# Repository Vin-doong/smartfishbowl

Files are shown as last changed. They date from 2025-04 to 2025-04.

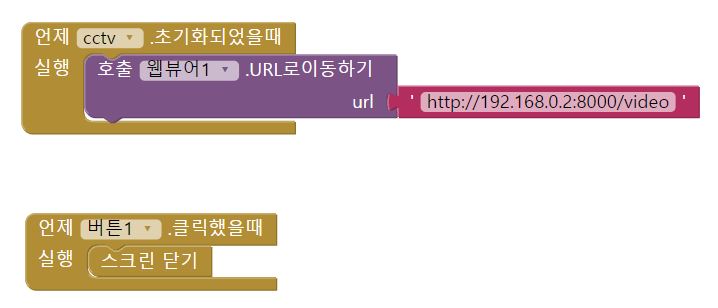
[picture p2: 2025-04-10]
앱제작파일/블록도/스마트어항CCTV.JPG

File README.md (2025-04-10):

# 스마트 어항 (Smart Fishbowl)

라즈베리파이를 활용한 IoT 기반 스마트 어항 시스템으로, 각종 센서를 통해 어항 환경을 모니터링하고 자동/수동으로 관리할 수 있습니다.

## 개요

집에서 물고기를 키우면서 항상 관리에 대한 어려움이 있습니다. 일상생활을 하면서 종종 물고기 먹이를 주는 것을 잊거나 물갈이 등을 잊어버릴 때가 있습니다. 어항 관리를 좀 더 편하게 하기 위해 스마트 어항이라는 작품을 개발했습니다.

사료 공급, 탁도 조절, 수위 체크 등 물고기를 키울 때 필요한 요소들을 라즈베리파이를 기반으로 자동화했습니다.

## 주요 기능

### 수동 모드
1. **센서값 모니터링**: 수위, 조도, 수온, 탁도, 온습도 센서값 출력
   - 새로고침 버튼 클릭 시 센서값 실시간 업데이트
2. **모터 수동 제어**: 
   - 먹이 공급 모터
   - 물 순환 모터
   - 물 공급 모터
3. **LED 조작**: ON/OFF 버튼으로 LED 제어
4. **CCTV 기능**: 파이카메라를 통한 물고기 실시간 관찰
5. **데이터 디스플레이**: 센서값을 LCD 및 앱에 표시

### 자동 모드
1. **조도 센서 기반 LED 제어**: 일정 조도값에 따라 자동으로 LED ON/OFF
2. **수위 센서 기반 물 공급 제어**: 일정 수위값에 도달 시 물 공급 모터 자동 동작
3. **탁도 센서 기반 물 순환 제어**: 일정 탁도값에 도달 시 물 순환 모터 자동 동작

## 하드웨어 구성요소

- 라즈베리파이 (메인 컨트롤러)
- 모터 드라이버 (L298N)
- 서보 모터 (사료 공급용)
- DC 모터 (물 순환 및 물 공급용)
- 각종 센서:
  - 수위 센서
  - 조도 센서
  - 수온 센서 (DS18B20)
  - 탁도 센서
  - 온습도 센서 (DHT11)
- LCD 디스플레이 (I2C)
- LED 조명
- 파이카메라
- PCF8591 ADC 컨버터 (아날로그 센서 인터페이스)

## 소프트웨어 구성

### 백엔드
- Python 기반 Flask 웹 서버
- GPIO 제어 라이브러리
- 센서 데이터 수집 및 처리 모듈
- 자동 제어 알고리즘

### 프론트엔드
- 모바일 애플리케이션 (MIT App Inventor로 개발)
- HTML/CSS 웹 인터페이스 (CCTV 화면용)

## 설치 및 실행 방법

1. 라즈베리파이에 필요한 라이브러리 설치:
```bash
sudo apt-get update
sudo apt-get install python3-pip
pip3 install flask
pip3 install Adafruit_DHT
pip3 install smbus
pip3 install picamera2
pip3 install opencv-python
pip3 install numpy
pip3 install pillow
```

2. 하드웨어 연결:
   - GPIO 핀 연결은 코드 내 설정 참조 (GPIO 5, 6, 13, 19, 21, 26 등 사용)
   - I2C 연결 (LCD, PCF8591)
   - 1-Wire 설정 (수온 센서용)

3. 코드 실행:
```bash
python3 finalfinalwork.py
```

4. 모바일 앱 설치:
   - App Inventor로 제작된 APK 파일 설치

## 코드 설명

### 메인 코드 (finalfinalwork.py)

메인 코드는 다음과 같은 섹션으로 구성되어 있습니다:

1. **라이브러리 임포트 및 초기화**
   - Flask, GPIO, 센서 라이브러리 등 임포트
   - GPIO 설정 및 PWM 초기화

2. **센서 데이터 수집 함수**
   - 각 센서별 데이터 읽기 함수
   - 온습도 센서를 위한 스레드 설정

3. **카메라 스트리밍 설정**
   - Picamera2 설정 및 프레임 캡처 함수

4. **웹 라우트 설정**
   - 메인 페이지, 자동 모드, 수동 모드, CCTV 등 엔드포인트 정의
   - 센서 데이터 표시 및 모터 제어 로직

### LCD 드라이버 (I2C_LCD_driver.py)

I2C를 통한 LCD 디스플레이 제어를 위한 드라이버 코드입니다.

### HTML 템플릿 (index4#2.html)

CCTV 기능을 위한 웹 인터페이스 HTML 파일입니다.

## 3D 프린팅 설계

프로젝트에는 다음과 같은 3D 프린팅 컴포넌트가 포함되어 있습니다:
- 파이카메라 거치대
- LED 거치대 및 LED 바
- LCD 케이스
- 컨트롤박스
- 먹이공급 케이스
- 물통 등

## 네트워크 통신

- TCP/IP 기반 통신
- 포트포워딩을 통한 외부 접속 지원
- Flask 웹서버를 통한 API 제공

## 앱 인터페이스

모바일 앱은 다음과 같은 기능을 제공합니다:
- 센서값 실시간 모니터링
- 수동 모드에서 각 컴포넌트 제어
- 자동 모드 활성화/비활성화
- CCTV 화면 보기

## 제작자

- 김상현(조장)
- 이순민

## 참고자료

- [VNC 화면설정](https://www.youtube.com/watch?v=LlXx9yVfQ0k)
- [PCF8591 사용법](https://blog.naver.com/tiled12/221791735227)
- [Picamera 작동](https://www.youtube.com/watch?v=kuJpdAf07WQ)
- [라즈베리파이 코드 자동실행](https://eggwhite0.tistory.com/73)
- [GPIO 라이브러리](https://abyz.me.uk/rpi/pigpio/index.html)
- [파이카메라 CCTV활용](https://www.youtube.com/watch?v=Y3IdUiFYhe8)
- [플라스크 예제](https://scribblinganything.tistory.com/400)
- [포트포워딩 설정](https://m.blog.naver.com/dsz08082/221871200736)

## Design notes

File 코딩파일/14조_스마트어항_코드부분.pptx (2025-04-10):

## 스마트 어항 (Smart Fishbowl)

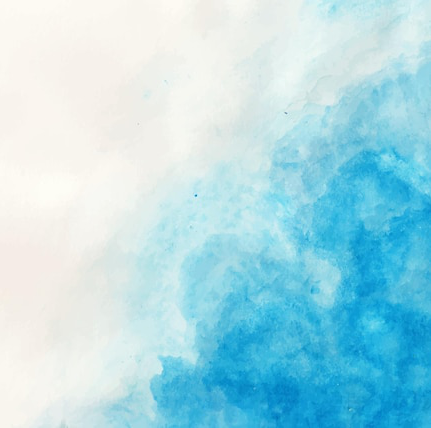
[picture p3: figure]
무료 벡터 블루 자세한 배경으로 수채화

조원:20202727 김상현
20201554 이순민

## Python 부분

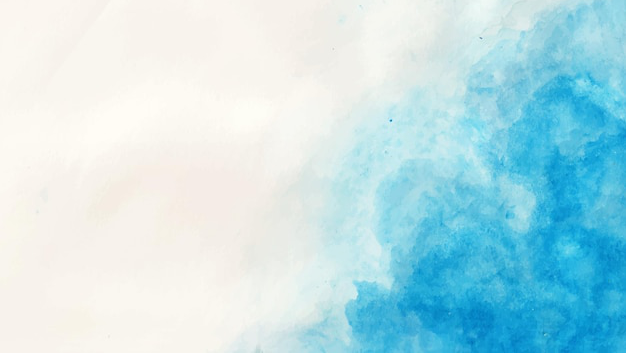
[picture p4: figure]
무료 벡터 블루 자세한 배경으로 수채화

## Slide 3

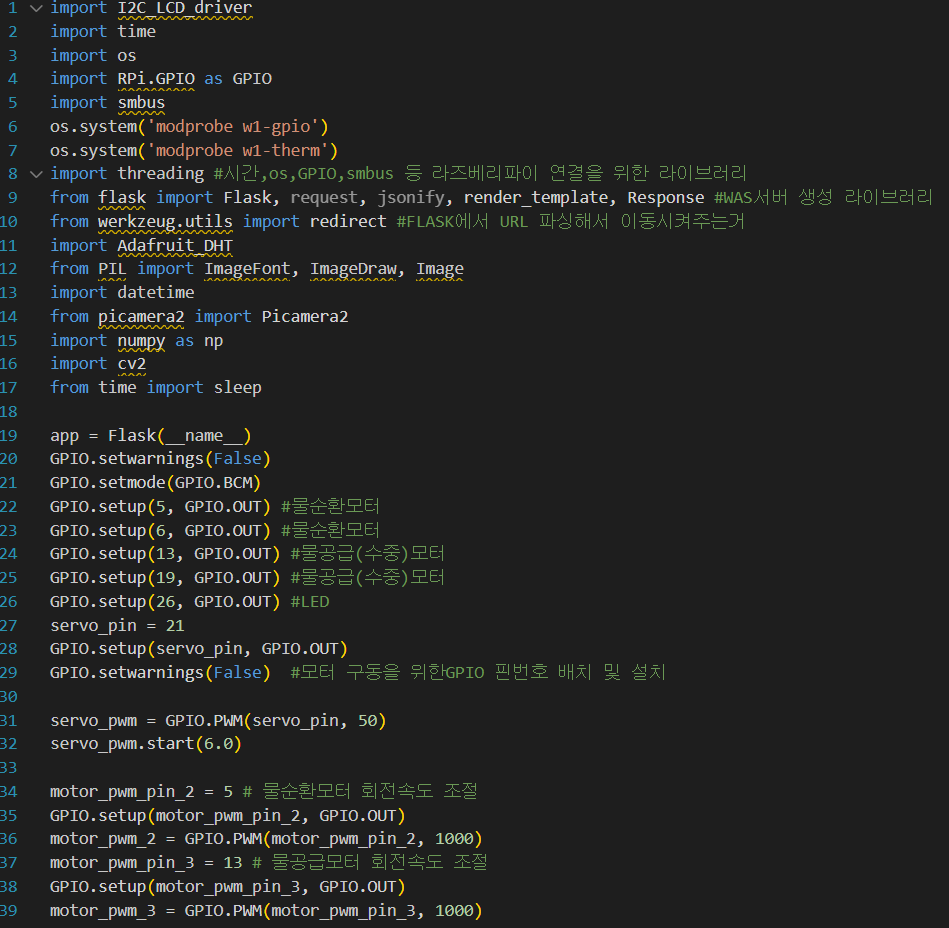
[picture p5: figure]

1~17 : 스마트 어항에 필요한 라이브러리 호출
19 : flask 웹 애플리케이션 서버 만들기 시작
21~39 : 모터 및 LED 셋업, 물순환, 물공급모터 회전속도 조절

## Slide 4

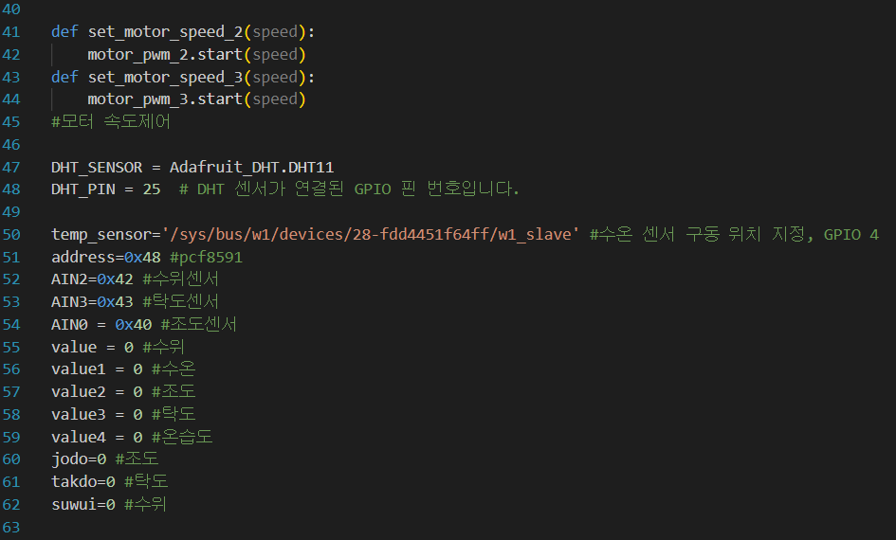
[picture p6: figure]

41~44 : 모터속도 제어 정의
47~48 : 온습도센서(DHT11)정의
50~62 : 스마트어항에 들어가는 센서들 정의

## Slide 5

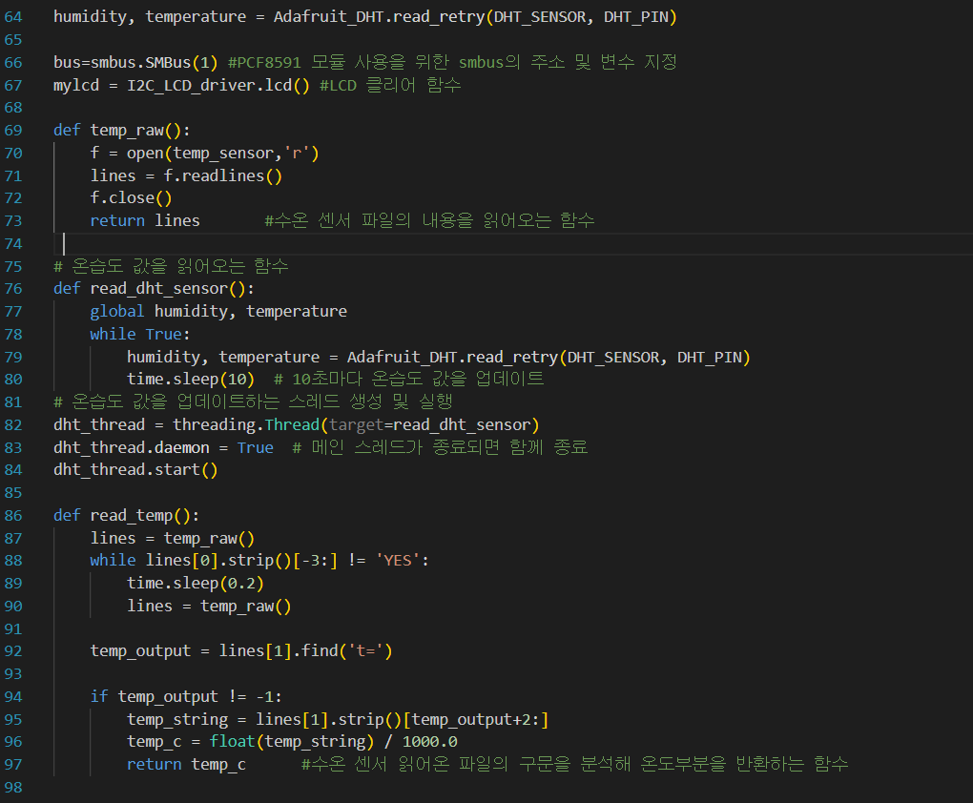
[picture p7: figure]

64 : 온습도 센서 불러오기
66 : PCF8591 모듈 사용
67 : LCD라이브러리 사용 정의
69~97 : 수온 및 온습도 센서 정의

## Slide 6

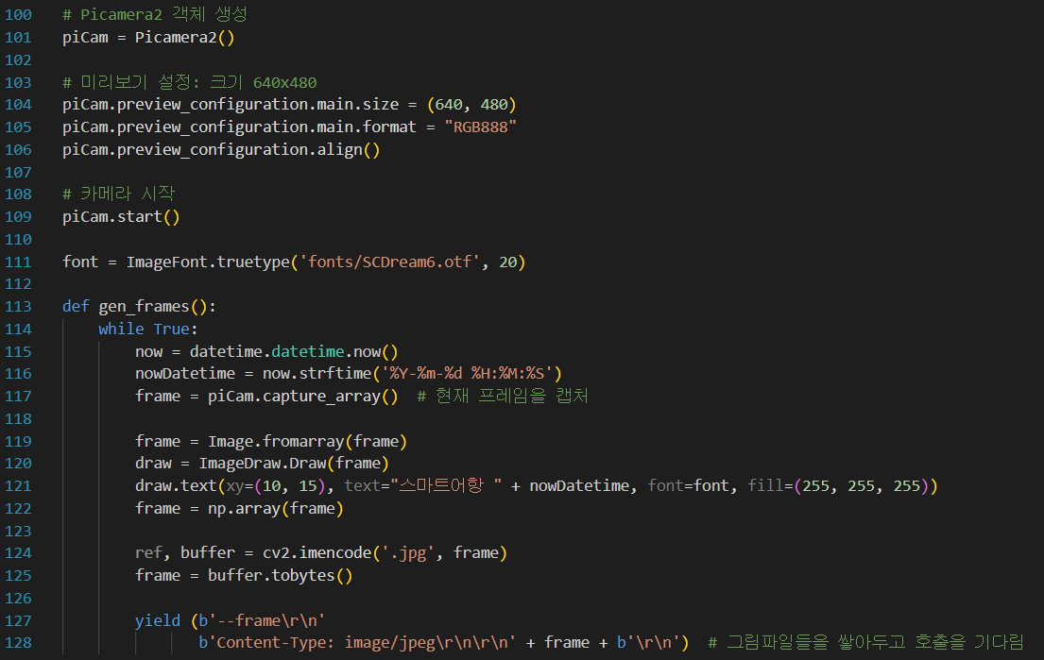
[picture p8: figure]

100 ~128 : 스마트어항 CCTV에 사용되는 파이카메라 세팅 및 화면(이미지파일)에 현재시간 표시

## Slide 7

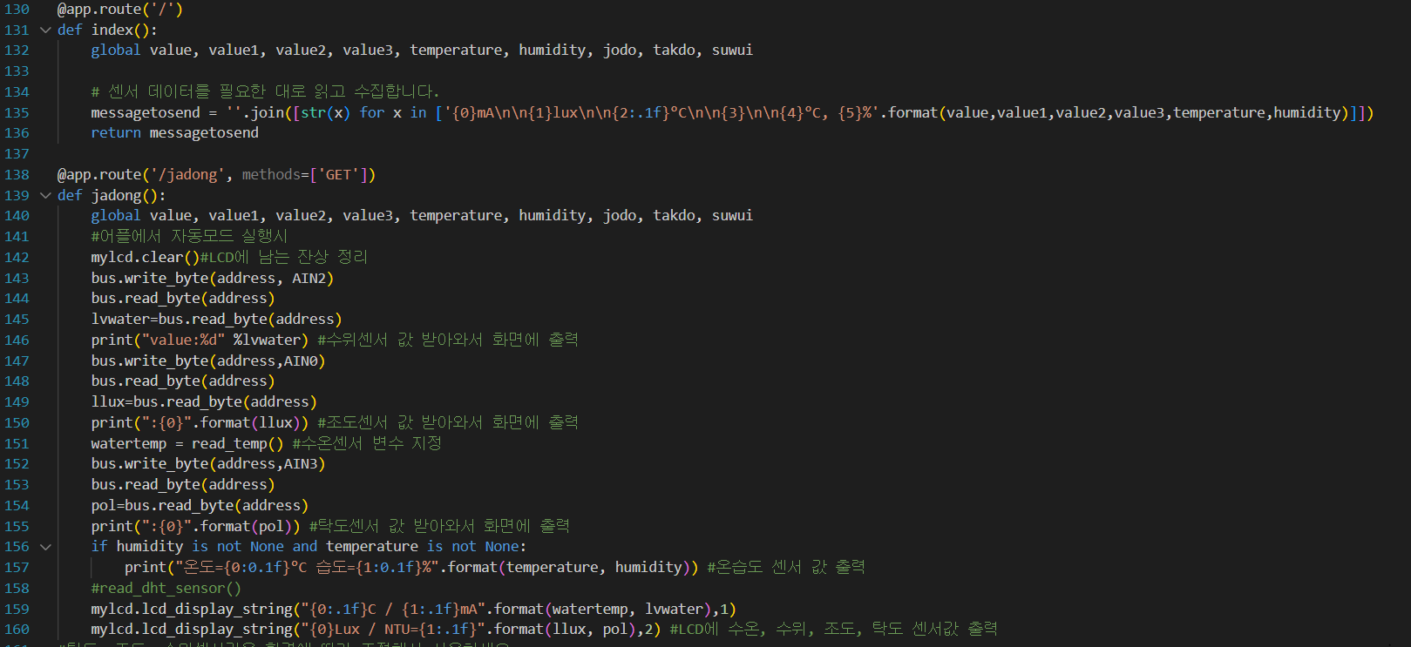
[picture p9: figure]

130~136 : flask 메인, 센서값 불러오기
138~160 : 자동모드 일 때 실행

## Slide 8

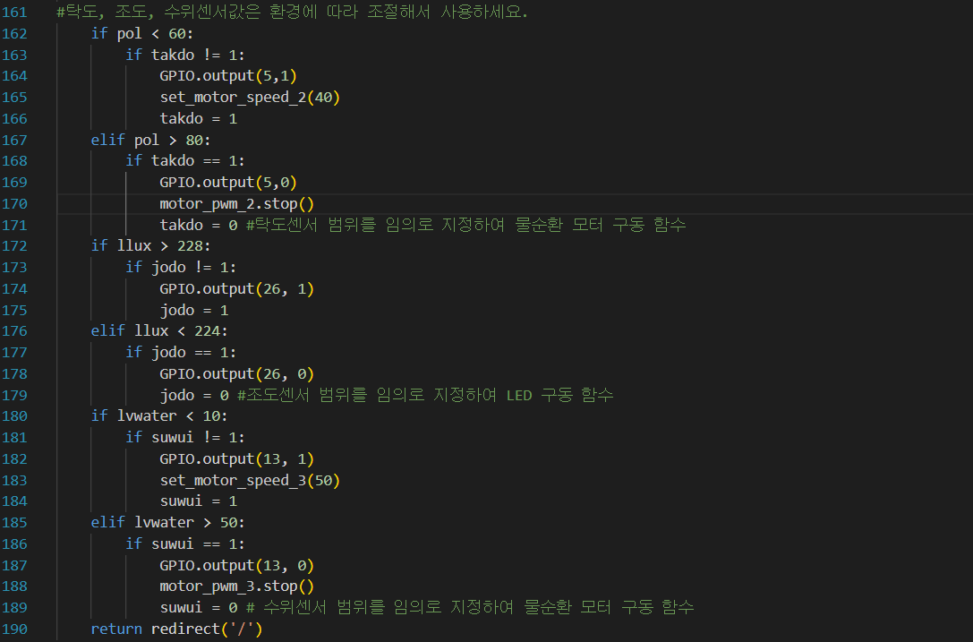
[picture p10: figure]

161~190 : 자동모드 일 때 실행조건 정의

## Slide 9

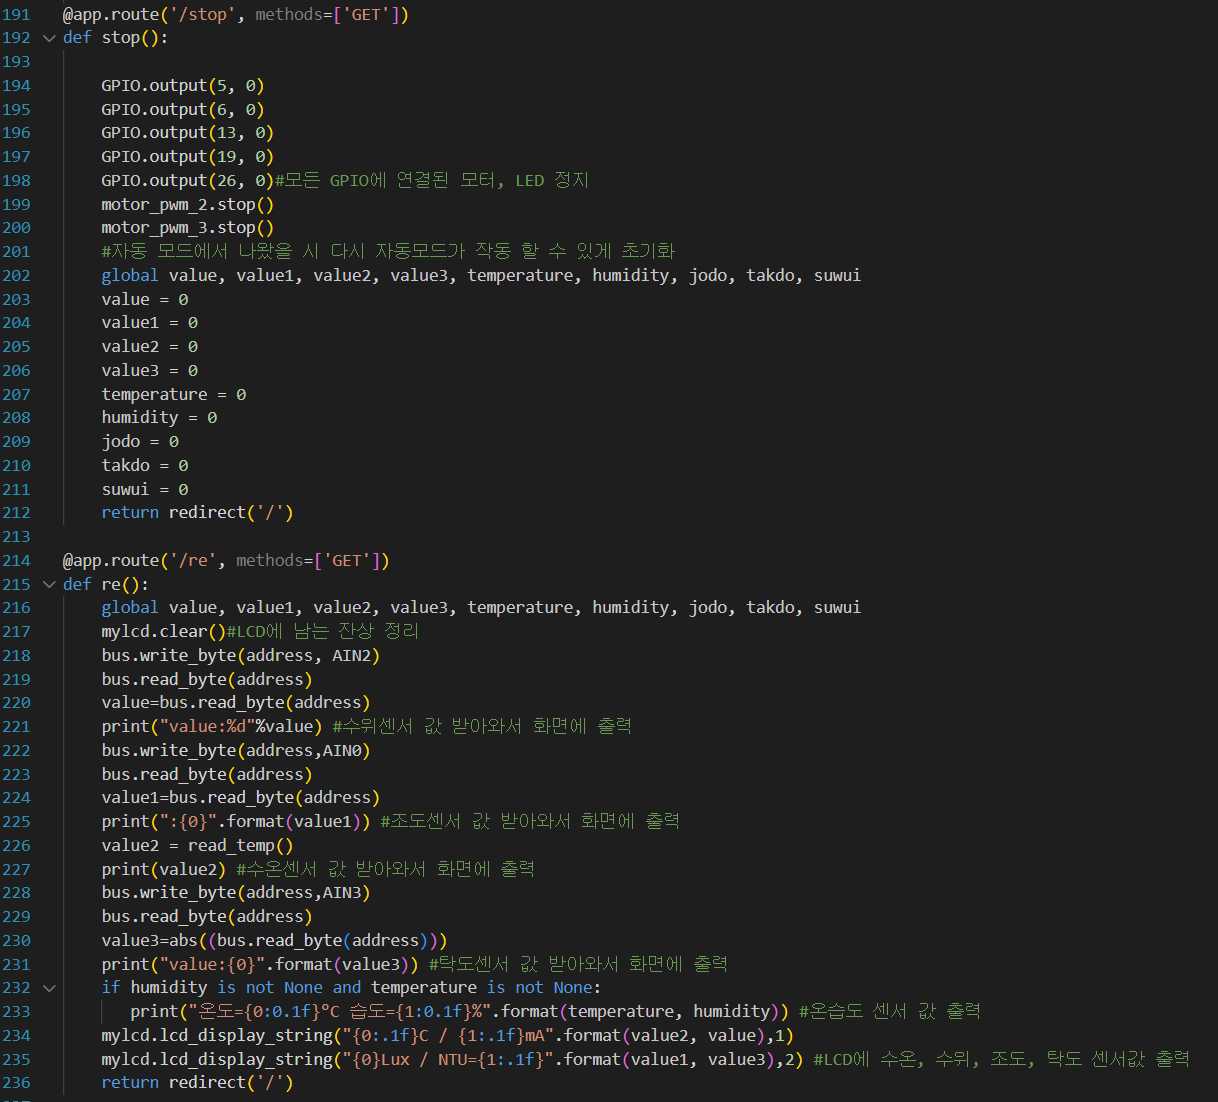
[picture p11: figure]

191~212 : 자동모드에서 정지 시(홈화면으로 돌아갈 때) 모터 및 LED 작동 정지
214~236 : 리셋버튼을 눌렀을 시 센서값을 받아오고 출력

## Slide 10

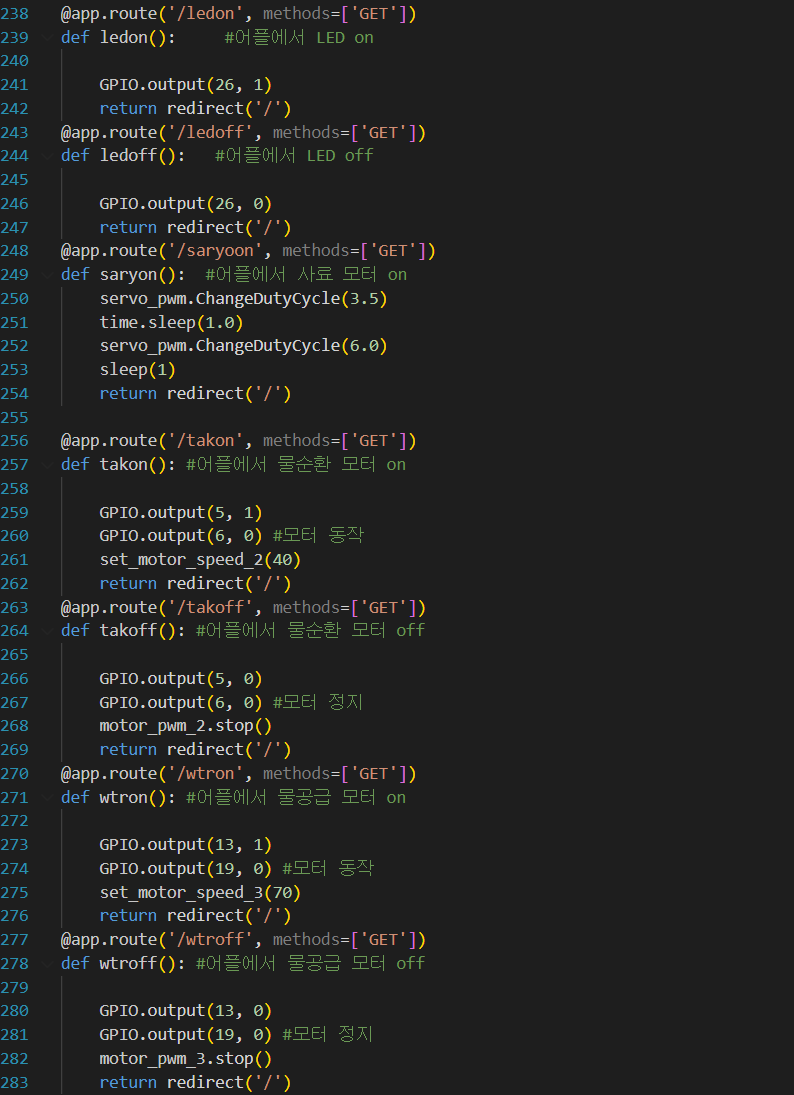
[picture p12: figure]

238~242 : LED on
244~247 : LED off
248~254 : 사료모터 on
256~262 : 물순환모터 on
263~269 : 물순환모터 off
270~276 : 물공급모터 on
277~283 : 물공급모터 off

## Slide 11

284~287 : CCTV 웹페이지
289~291 : CCTV 웹페이지에 파이카메라의 영상(이미지)를 반환
294~295 : flask 실행

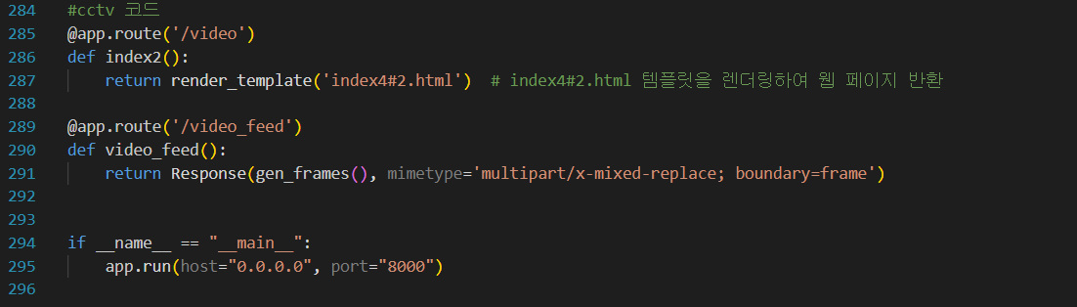
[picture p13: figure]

## CCTV 웹 부분

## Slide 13

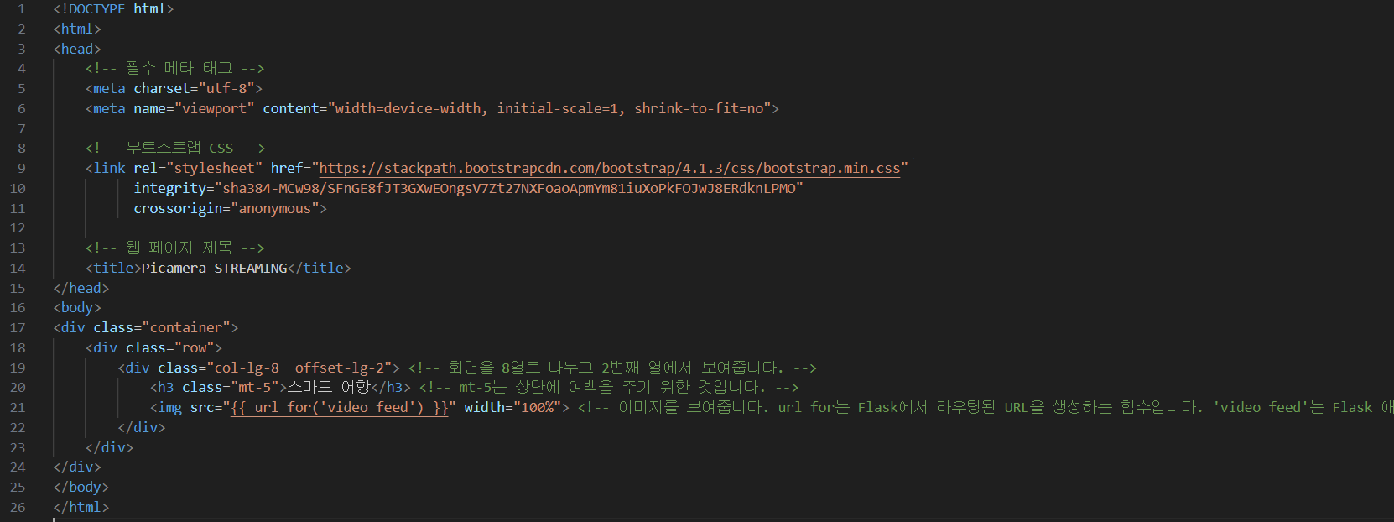
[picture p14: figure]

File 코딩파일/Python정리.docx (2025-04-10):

# I2C LCD 모듈을 사용하기 위한 드라이버 및 기타 라이브러리 임포트

import I2C_LCD_driver

import time

# 운영 체제 관련 기능을 사용하기 위한 라이브러리 임포트

import os

# Raspberry Pi GPIO 라이브러리 임포트

import RPi.GPIO as GPIO

# I2C 통신을 위한 라이브러리 임포트

import smbus

# DS18B20 온도 센서를 사용하기 위한 라이브러리 설정

os.system('modprobe w1-gpio')

os.system('modprobe w1-therm')

# 스레딩을 위한 라이브러리 임포트

import threading

# Flask 웹 애플리케이션을 위한 라이브러리 임포트

from flask import Flask, request, jsonify, render_template, Response

# 웹 페이지 리다이렉션을 위한 라이브러리 임포트

from werkzeug.utils import redirect

# Adafruit_DHT 라이브러리를 사용하여 DHT 센서를 위한 라이브러리 임포트

import Adafruit_DHT

# 이미지 및 텍스트 관련 작업을 위한 라이브러리 임포트

from PIL import ImageFont, ImageDraw, Image

# 현재 시간 및 날짜를 처리하기 위한 라이브러리 임포트

import datetime

# Picamera2 모듈을 사용하기 위한 라이브러리 임포트

from picamera2 import Picamera2

# 이미지 처리를 위한 라이브러리 임포트

import numpy as np

import cv2

# 시간 지연을 위한 sleep 함수 임포트

from time import sleep

# Flask 웹 애플리케이션 인스턴스 생성

app = Flask(__name__)

# GPIO 설정 및 초기화

GPIO.setwarnings(False)

GPIO.setmode(GPIO.BCM)

# 물순환모터 및 물공급(수중)모터 및 LED를 제어하는 GPIO 핀 설정

GPIO.setup(5, GPIO.OUT) # 물순환모터

GPIO.setup(6, GPIO.OUT) # 물순환모터

GPIO.setup(13, GPIO.OUT) # 물공급(수중)모터

GPIO.setup(19, GPIO.OUT) # 물공급(수중)모터

GPIO.setup(26, GPIO.OUT) # LED

# 서보 모터를 제어하는 GPIO 핀 설정

servo_pin = 21

GPIO.setup(servo_pin, GPIO.OUT)

# 서보 모터 PWM 설정 및 시작

servo_pwm = GPIO.PWM(servo_pin, 50)

servo_pwm.start(6.0)

# 물순환모터 및 물공급모터의 PWM 설정

motor_pwm_pin_2 = 5 # 물순환모터 회전속도 조절

GPIO.setup(motor_pwm_pin_2, GPIO.OUT)

motor_pwm_2 = GPIO.PWM(motor_pwm_pin_2, 1000)

motor_pwm_pin_3 = 13 # 물공급모터 회전속도 조절

GPIO.setup(motor_pwm_pin_3, GPIO.OUT)

motor_pwm_3 = GPIO.PWM(motor_pwm_pin_3, 1000)

def set_motor_speed_2(speed):

motor_pwm_2.start(speed)

def set_motor_speed_3(speed):

motor_pwm_3.start(speed)

# 모터 속도 제어 함수

# DHT11 온습도 센서 설정

DHT_SENSOR = Adafruit_DHT.DHT11

DHT_PIN = 25 # DHT 센서가 연결된 GPIO 핀 번호

# 수온 센서 설정

temp_sensor = '/sys/bus/w1/devices/28-fdd4451f64ff/w1_slave'

# PCF8591 아날로그-디지털 컨버터 주소 및 변수 설정

address = 0x48

AIN2 = 0x42 # 수위센서

AIN3 = 0x43 # 탁도센서

AIN0 = 0x40 # 조도센서

# 초기 변수 설정

value = 0 # 수위

value1 = 0 # 수온

value2 = 0 # 조도

value3 = 0 # 탁도

value4 = 0 # 온습도

# DHT11 센서에서 습도 및 온도 읽기

humidity, temperature = Adafruit_DHT.read_retry(DHT_SENSOR, DHT_PIN)

# PCF8591 모듈 사용을 위한 smbus 주소 설정

bus = smbus.SMBus(1)

# I2C LCD 모듈 인스턴스 생성

mylcd = I2C_LCD_driver.lcd()

# 수온 센서 파일의 내용을 읽어오는 함수

def temp_raw():

f = open(temp_sensor, 'r')

lines = f.readlines()

f.close()

return lines

# 온습도 값을 읽어오는 함수

def read_dht_sensor():

global humidity, temperature

while True:

humidity, temperature = Adafruit_DHT.read_retry(DHT_SENSOR, DHT_PIN)

time.sleep(10) # 10초마다 온습도 값을 업데이트

# 온습도 값을 업데이트하는 스레드 생성 및 실행

dht_thread = threading.Thread(target=read_dht_sensor)

dht_thread.daemon = True # 메인 스레드가 종료되면 함께 종료

dht_thread.start()

# 수온 센서 파일에서 온도를 읽어오는 함수

def read_temp():

lines = temp_raw()

while lines[0].strip()[-3:] != 'YES':

time.sleep(0.2)

lines = temp_raw()

temp_output = lines[1].find('t=')

if temp_output != -1:

temp_string = lines[1].strip()[temp_output + 2:]

temp_c = float(temp_string) / 1000.0

return temp_c # 수온 센서 읽어온 파일의 구문을 분석해 온도 부분을 반환하는 함수

# Picamera2 객체 생성

piCam = Picamera2()

# 미리보기 설정: 크기 640x480

piCam.preview_configuration.main.size = (640, 480)

piCam.preview_configuration.main.format = "RGB888"

piCam.preview_configuration.align()

# 카메라 시작

piCam.start()

# 한글 폰트 설정

font = ImageFont.truetype('fonts/SCDream6.otf', 20)

# 영상 프레임을 생성하는 함수

def gen_frames():

while True:

now = datetime.datetime.now()

nowDatetime = now.strftime('%Y-%m-%d %H:%M:%S')

frame = piCam.capture_array() # 현재 프레임을 캡처

frame = Image.fromarray(frame)

draw = ImageDraw.Draw(frame)

draw.text(xy=(10, 15), text="스마트어항 " + nowDatetime, font=font, fill=(255, 255, 255))

frame = np.array(frame)

ref, buffer = cv2.imencode('.jpg', frame)

frame = buffer.tobytes()

yield (b'--frame\r\n'

b'Content-Type: image/jpeg\r\n\r\n' + frame + b'\r\n') # 그림파일들을 쌓아두고 호출을 기다림

# 홈 페이지

@app.route('/')

def index():

global value, value1, value2, value3, temperature, humidity, jodo, takdo, suwui

# 센서 데이터를 필요한 대로 읽고 수집합니다.

messagetosend = ''.join([str(x) for x in ['{0}mA\n\n{1}dark\n\n{2:.1f}°C\n\n{3}\n\n{4}°C, {5}%'.format(value, value1, value2, value3, temperature, humidity)]])

return messagetosend

# 자동 모드 실행 시 수행되는 함수

@app.route('/jadong', methods=['GET'])

def jadong():

global value, value1, value2, value3, temperature, humidity, jodo, takdo, suwui

# 어플에서 자동모드 실행 시

mylcd.clear() # LCD에 남는 잔상 정리

bus.write_byte(address, AIN2)

bus.read_byte(address)

lvwater = bus.read_byte(address)

print("value: %d" % lvwater) # 수위센서 값 받아와서 화면에 출력

bus.write_byte(address, AIN0)

bus.read_byte(address)

llux = bus.read_byte(address)

print(":{0}".format(llux)) # 조도센서 값 받아와서 화면에 출력

watertemp = read_temp() # 수온센서 변수 지정

bus.write_byte(address, AIN3)

bus.read_byte(address)

pol = bus.read_byte(address)

print(":{0}".format(pol)) # 탁도센서 값 받아와서 화면에 출력

if humidity is not None and temperature is not None:

print("온도={0:0.1f}°C 습도={1:0.1f}%".format(temperature, humidity)) # 온습도 센서 값 출력

# read_dht_sensor()

mylcd.lcd_display_string("{0:.1f}C / {1:.1f}mA".format(watertemp, lvwater), 1)

mylcd.lcd_display_string("{0}Da / NTU={1:.1f}".format(llux, pol), 2) # LCD에 수온, 수위, 조도, 탁도 센서값 출력

# 탁도, 조도, 수위센서값은 환경에 따라 조절해서 사용하세요.

# 탁도 범위에 따른 물순환 모터 동작

if pol < 60:

GPIO.output(5, 1)

set_motor_speed_2(40)

elif pol > 80:

GPIO.output(5, 0)

motor_pwm_2.stop()

# 탁도센서 범위를 임의로 지정하여 물순환 모터 구동 함수

# 조도 범위에 따른 LED 동작

if llux > 228:

GPIO.output(26, 1)

elif llux < 224:

GPIO.output(26, 0)

# 조도센서 범위를 임의로 지정하여 LED 구동 함수

# 수위센서 범위에 따른 물순환 모터 동작

if lvwater < 10:

GPIO.output(13, 1)

set_motor_speed_3(50)

elif lvwater > 50:

GPIO.output(13, 0)

motor_pwm_3.stop()

# 수위센서 범위를 임의로 지정하여 물순환 모터 구동 함수

return redirect('/')

# 모든 GPIO에 연결된 모터 및 LED 정지

@app.route('/stop', methods=['GET'])

def stop():

GPIO.output(5, 0)

GPIO.output(6, 0)

GPIO.output(13, 0)

GPIO.output(19, 0)

GPIO.output(26, 0)

motor_pwm_2.stop()

motor_pwm_3.stop()

# 자동 모드에서 나왔을 시 다시 자동모드가 작동 할 수 있게 초기화

global value, value1, value2, value3, temperature, humidity

value = 0

value1 = 0

value2 = 0

value3 = 0

temperature = 0

humidity = 0

return redirect('/')

# 실시간 센서 데이터 표시 페이지

@app.route('/re', methods=['GET'])

def re():

global value, value1, value2, value3, temperature, humidity

mylcd.clear() # LCD에 남는 잔상 정리

bus.write_byte(address, AIN2)

bus.read_byte(address)

value = bus.read_byte(address)

print("value: %d" % value) # 수위센서 값 받아와서 화면에 출력

bus.write_byte(address, AIN0)

bus.read_byte(address)

value1 = bus.read_byte(address)

print(":{0}".format(value1)) # 조도센서 값 받아와서 화면에 출력

value2 = read_temp()

print(value2) # 수온센서 값 받아와서 화면에 출력

bus.write_byte(address, AIN3)

bus.read_byte(address)

value3 = abs((bus.read_byte(address)))

print("value: {0}".format(value3)) # 탁도센서 값 받아와서 화면에 출력

if humidity is not None and temperature is not None:

print("온도={0:0.1f}°C 습도={1:0.1f}%".format(temperature, humidity)) # 온습도 센서 값 출력

mylcd.lcd_display_string("{0:.1f}C / {1:.1f}mA".format(value2, value), 1)

mylcd.lcd_display_string("{0}Da / NTU={1:.1f}".format(value1, value3), 2) # LCD에 수온, 수위, 조도, 탁도 센서값 출력

return redirect('/')

# LED를 켜는 함수

@app.route('/ledon', methods=['GET'])

def ledon():

GPIO.output(26, 1)

return redirect('/')

# LED를 끄는 함수

@app.route('/ledoff', methods=['GET'])

def ledoff():

GPIO.output(26, 0)

return redirect('/')

# 사료 공급 모터를 동작시키는 함수

@app.route('/saryoon', methods=['GET'])

def saryon():

servo_pwm.ChangeDutyCycle(3.5)

time.sleep(1.0)

servo_pwm.ChangeDutyCycle(6.0)

sleep(1)

return redirect('/')

# 물순환 모터를 동작시키는 함수

@app.route('/takon', methods=['GET'])

def takon():

GPIO.output(5, 1)

GPIO.output(6, 0) # 모터 동작

set_motor_speed_2(40)

return redirect('/')

# 물순환 모터를 정지시키는 함수

@app.route('/takoff', methods=['GET'])

def takoff():

GPIO.output(5, 0)

GPIO.output(6, 0) # 모터 정지

motor_pwm_2.stop()

return redirect('/')

# 물공급 모터를 동작시키는 함수

@app.route('/wtron', methods=['GET'])

def wtron():

GPIO.output(13, 1)

GPIO.output(19, 0) # 모터 동작

set_motor_speed_3(70)

return redirect('/')

# 물공급 모터를 정지시키는 함수

@app.route('/wtroff', methods=['GET'])

def wtroff():

GPIO.output(13, 0)

GPIO.output(19, 0) # 모터 정지

motor_pwm_3.stop()

return redirect('/')

# CCTV 영상 스트리밍 페이지

@app.route('/video')

def index2():

return render_template('index4#2.html') # index4#2.html 템플릿을 렌더링하여 웹 페이지 반환

# CCTV 영상 스트리밍을 위한 URL

@app.route('/video_feed')

def video_feed():

return Response(gen_frames(), mimetype='multipart/x-mixed-replace; boundary=frame')

# Flask 애플리케이션 실행

if __name__ == "__main__":

app.run(host="0.0.0.0", port="8000")

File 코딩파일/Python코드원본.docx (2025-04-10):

import I2C_LCD_driver

import time

import os

import RPi.GPIO as GPIO

import smbus

os.system('modprobe w1-gpio')

os.system('modprobe w1-therm')

import threading #시간,os,GPIO,smbus 등 라즈베리파이 연결을 위한 라이브러리

from flask import Flask, request, jsonify, render_template, Response #WAS서버 생성 라이브러리

from werkzeug.utils import redirect #FLASK에서 URL 파싱해서 이동시켜주는거

import Adafruit_DHT

from PIL import ImageFont, ImageDraw, Image

import datetime

from picamera2 import Picamera2

import numpy as np

import cv2

from time import sleep

app = Flask(__name__)

GPIO.setwarnings(False)

GPIO.setmode(GPIO.BCM)

GPIO.setup(5, GPIO.OUT) #물순환모터

GPIO.setup(6, GPIO.OUT) #물순환모터

GPIO.setup(13, GPIO.OUT) #물공급(수중)모터

GPIO.setup(19, GPIO.OUT) #물공급(수중)모터

GPIO.setup(26, GPIO.OUT) #LED

servo_pin = 21

GPIO.setup(servo_pin, GPIO.OUT)

GPIO.setwarnings(False) #모터 구동을 위한GPIO 핀번호 배치 및 설치

servo_pwm = GPIO.PWM(servo_pin, 50)

servo_pwm.start(6.0)

motor_pwm_pin_2 = 5 # 물순환모터 회전속도 조절

GPIO.setup(motor_pwm_pin_2, GPIO.OUT)

motor_pwm_2 = GPIO.PWM(motor_pwm_pin_2, 1000)

motor_pwm_pin_3 = 13 # 물공급모터 회전속도 조절

GPIO.setup(motor_pwm_pin_3, GPIO.OUT)

motor_pwm_3 = GPIO.PWM(motor_pwm_pin_3, 1000)

#모터 속도제어

def set_motor_speed_2(speed):

motor_pwm_2.start(speed)

def set_motor_speed_3(speed):

motor_pwm_3.start(speed)

#모터 속도제어

DHT_SENSOR = Adafruit_DHT.DHT11

DHT_PIN = 25 # DHT 센서가 연결된 GPIO 핀 번호입니다.

temp_sensor='/sys/bus/w1/devices/28-fdd4451f64ff/w1_slave' #수온 센서 구동 위치 지정, GPIO 4

address=0x48 #pcf8591

AIN2=0x42 #수위센서

AIN3=0x43 #탁도센서

AIN0 = 0x40 #조도센서

value = 0 #수위

value1 = 0 #수온

value2 = 0 #조도

value3 = 0 #탁도

value4 = 0 #온습도

humidity, temperature = Adafruit_DHT.read_retry(DHT_SENSOR, DHT_PIN)

bus=smbus.SMBus(1) #PCF8591 모듈 사용을 위한 smbus의 주소 및 변수 지정

mylcd = I2C_LCD_driver.lcd() #LCD 클리어 함수

def temp_raw():

f = open(temp_sensor,'r')

lines = f.readlines()

f.close()

return lines #수온 센서 파일의 내용을 읽어오는 함수

# 온습도 값을 읽어오는 함수

def read_dht_sensor():

global humidity, temperature

while True:

humidity, temperature = Adafruit_DHT.read_retry(DHT_SENSOR, DHT_PIN)

time.sleep(10) # 10초마다 온습도 값을 업데이트

# 온습도 값을 업데이트하는 스레드 생성 및 실행

dht_thread = threading.Thread(target=read_dht_sensor)

dht_thread.daemon = True # 메인 스레드가 종료되면 함께 종료

dht_thread.start()

def read_temp():

lines = temp_raw()

while lines[0].strip()[-3:] != 'YES':

time.sleep(0.2)

lines = temp_raw()

temp_output = lines[1].find('t=')

if temp_output != -1:

temp_string = lines[1].strip()[temp_output+2:]

temp_c = float(temp_string) / 1000.0

return temp_c #수온 센서 읽어온 파일의 구문을 분석해 온도부분을 반환하는 함수

# Picamera2 객체 생성

piCam = Picamera2()

# 미리보기 설정: 크기 640x480

piCam.preview_configuration.main.size = (640, 480)

piCam.preview_configuration.main.format = "RGB888"

piCam.preview_configuration.align()

# 카메라 시작

piCam.start()

font = ImageFont.truetype('fonts/SCDream6.otf', 20)

def gen_frames():

while True:

now = datetime.datetime.now()

nowDatetime = now.strftime('%Y-%m-%d %H:%M:%S')

frame = piCam.capture_array() # 현재 프레임을 캡처

frame = Image.fromarray(frame)

draw = ImageDraw.Draw(frame)

draw.text(xy=(10, 15), text="스마트어항 " + nowDatetime, font=font, fill=(255, 255, 255))

frame = np.array(frame)

ref, buffer = cv2.imencode('.jpg', frame)

frame = buffer.tobytes()

yield (b'--frame\r\n'

b'Content-Type: image/jpeg\r\n\r\n' + frame + b'\r\n') # 그림파일들을 쌓아두고 호출을 기다림

@app.route('/')

def index():

global value, value1, value2, value3, temperature, humidity

# 센서 데이터를 필요한 대로 읽고 수집합니다.

messagetosend = ''.join([str(x) for x in ['{0}mA\n\n{1}dark\n\n{2:.1f}°C\n\n{3}\n\n{4}°C, {5}%'.format(value,value1,value2,value3,temperature,humidity)]])

return messagetosend

@app.route('/jadong', methods=['GET'])

def jadong():

global value, value1, value2, value3, temperature, humidity

#어플에서 자동모드 실행시

mylcd.clear()#LCD에 남는 잔상 정리

bus.write_byte(address, AIN2)

bus.read_byte(address)

lvwater=bus.read_byte(address)

print("value:%d" %lvwater) #수위센서 값 받아와서 화면에 출력

bus.write_byte(address,AIN0)

bus.read_byte(address)

llux=bus.read_byte(address)

print(":{0}".format(llux)) #조도센서 값 받아와서 화면에 출력

watertemp = read_temp() #수온센서 변수 지정

bus.write_byte(address,AIN3)

bus.read_byte(address)

pol=bus.read_byte(address)

print(":{0}".format(pol)) #탁도센서 값 받아와서 화면에 출력

if humidity is not None and temperature is not None:

print("온도={0:0.1f}°C 습도={1:0.1f}%".format(temperature, humidity)) #온습도 센서 값 출력

mylcd.lcd_display_string("{0:.1f}C/{1:.1f}mA".format(watertemp, lvwater),1)

mylcd.lcd_display_string("{0}da/NTU={1:.1f}".format(llux, pol),2) #LCD에 수온, 수위, 조도, 탁도 센서값 출력

#탁도, 조도, 수위센서 환경에 따라 조절해서 사용하세요. 0920 수정

if pol < 60:

GPIO.output(5,1)

set_motor_speed_2(40)

elif pol > 80:

GPIO.output(5,0)

motor_pwm_2.stop()

if llux > 236:

GPIO.output(26, 1)

elif llux < 234:

GPIO.output(26, 0)

if lvwater < 10:

GPIO.output(13, 1)

set_motor_speed_3(70)

elif lvwater > 0:

GPIO.output(13, 0)

motor_pwm_3.stop()

return redirect('/')

@app.route('/stop', methods=['GET'])

def stop():

GPIO.output(5, 0)

GPIO.output(6, 0)

GPIO.output(13, 0)

GPIO.output(19, 0)

GPIO.output(26, 0)#모든 GPIO에 연결된 모터, LED 정지

motor_pwm_2.stop()

motor_pwm_3.stop()

global value, value1, value2, value3, temperature, humidity

value = 0

value1 = 0

value2 = 0

value3 = 0

temperature = 0

humidity = 0

return redirect('/')

@app.route('/re', methods=['GET'])

def re():

global value, value1, value2, value3, temperature, humidity#, jodo, takdo, suwui

mylcd.clear()#LCD에 남는 잔상 정리

bus.write_byte(address, AIN2)

bus.read_byte(address)

value=bus.read_byte(address)

print("value:%d"%value) #수위센서 값 받아와서 화면에 출력

bus.write_byte(address,AIN0)

bus.read_byte(address)

value1=bus.read_byte(address)

print(":{0}".format(value1)) #조도센서 값 받아와서 화면에 출력

value2 = read_temp()

print(value2) #수온센서 값 받아와서 화면에 출력

bus.write_byte(address,AIN3)

bus.read_byte(address)

value3=abs((bus.read_byte(address)))

print("value:{0}".format(value3)) #탁도센서 값 받아와서 화면에 출력

if humidity is not None and temperature is not None:

print("온도={0:0.1f}°C 습도={1:0.1f}%".format(temperature, humidity)) #온습도 센서 값 출력

mylcd.lcd_display_string("{0:.1f}C/{1:.1f}mA".format(value2, value),1)

mylcd.lcd_display_string("{0}da/NTU={1:.1f}".format(value1, value3),2) #LCD에 수온, 수위, 조도, 탁도 센서값 출력

return redirect('/')

@app.route('/ledon', methods=['GET'])

def ledon(): #어플에서 LED on

GPIO.output(26, 1)

return redirect('/')

@app.route('/ledoff', methods=['GET'])

def ledoff(): #어플에서 LED off

GPIO.output(26, 0)

return redirect('/')

@app.route('/saryoon', methods=['GET'])

def saryon(): #어플에서 사료 모터 on

servo_pwm.ChangeDutyCycle(3.5)

time.sleep(1.0)

servo_pwm.ChangeDutyCycle(6.0)

sleep(1)

return redirect('/')

@app.route('/takon', methods=['GET'])

def takon(): #어플에서 물순환 모터 on

GPIO.output(5, 1)

GPIO.output(6, 0) #모터 동작

set_motor_speed_2(40)

return redirect('/')

@app.route('/takoff', methods=['GET'])

def takoff(): #어플에서 물순환 모터 off

GPIO.output(5, 0)

GPIO.output(6, 0) #모터 정지

motor_pwm_2.stop()

return redirect('/')

@app.route('/wtron', methods=['GET'])

def wtron(): #어플에서 물공급 모터 on

GPIO.output(13, 1)

GPIO.output(19, 0) #모터 동작

set_motor_speed_3(70)#0920 수정

return redirect('/')

@app.route('/wtroff', methods=['GET'])

def wtroff(): #어플에서 물공급 모터 off

GPIO.output(13, 0)

GPIO.output(19, 0) #모터 정지

motor_pwm_3.stop()#0920 수정

return redirect('/')

#cctv 코드

@app.route('/video')

def index2():

return render_template('index4#2.html') # index4#2.html 템플릿을 렌더링하여 웹 페이지 반환

@app.route('/video_feed')

def video_feed():

return Response(gen_frames(), mimetype='multipart/x-mixed-replace; boundary=frame')

if __name__ == "__main__":

app.run(host="0.0.0.0", port="8000")

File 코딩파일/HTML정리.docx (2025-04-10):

<!DOCTYPE html>

<html>

<head>

<!-- 필수 메타 태그 -->

<meta charset="utf-8">

<meta name="viewport" content="width=device-width, initial-scale=1, shrink-to-fit=no">

<!-- 부트스트랩 CSS -->

<link rel="stylesheet" href="https://stackpath.bootstrapcdn.com/bootstrap/4.1.3/css/bootstrap.min.css"

integrity="sha384-MCw98/SFnGE8fJT3GXwEOngsV7Zt27NXFoaoApmYm81iuXoPkFOJwJ8ERdknLPMO" crossorigin="anonymous">

<title>14조 스마트어항</title>

<style>

body {

background-color: #bff2ff; /* 배경 색상을 원하는 색으로 지정 */

}

</style>

</head>

<body>

<div class="container">

<div class="row">

<div class="col-lg-8 offset-lg-2 text-center"> <!-- 화면을 8열로 나누고 2번째 열에서 보여주며 가운데 정렬 -->

<h3 class="mt-5">14조 스마트어항</h3> <!-- 페이지 제목을 표시하며 위쪽으로 5단계의 공백을 추가 -->

<img src="{{ url_for('video_feed') }}" width="100%"> <!-- 영상 스트리밍을 보여줌 -->

</div>

</div>

</div>

</body>

</html>

meta 태그: 문서의 문자 인코딩 및 뷰포트 설정을 지정합니다.

link 태그: Bootstrap CSS를 사용하기 위한 외부 스타일 시트를 연결합니다.

style 태그: 페이지의 스타일을 설정합니다. 현재는 배경 색상을 지정하고 있습니다.

container, row, col 클래스: Bootstrap 그리드 시스템을 활용하여 페이지를 레이아웃합니다.

h3 태그: 페이지 상단에 제목을 표시합니다.

img 태그: CCTV 영상 스트리밍을 표시하기 위한 이미지 태그입니다. url_for('video_feed')는 Flask 라우터에서 정의한 /video_feed URL에 대한 주소를 동적으로 생성합니다.

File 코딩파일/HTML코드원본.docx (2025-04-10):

<html>

<head>

<!-- Required meta tags -->

<meta charset="utf-8">

<meta name="viewport" content="width=device-width, initial-scale=1, shrink-to-fit=no">

<!-- Bootstrap CSS -->

<link rel="stylesheet" href="https://stackpath.bootstrapcdn.com/bootstrap/4.1.3/css/bootstrap.min.css"

integrity="sha384-MCw98/SFnGE8fJT3GXwEOngsV7Zt27NXFoaoApmYm81iuXoPkFOJwJ8ERdknLPMO" crossorigin="anonymous">

<title>14조 스마트어항</title>

<style>

body {

background-color: #bff2ff; /* 원하는 배경 색상으로 변경 */

}

</style>

</head>

<body>

<div class="container">

<div class="row">

<div class="col-lg-8 offset-lg-2 text-center"> <!-- 화면 8열로 나누고 2번째 열에서 보여줌 1004 text-center 추가 -->

<h3 class="mt-5">14조 스마트어항</h3> <!-- mt-5는 공백을 주기 위한 것 -->

<img src="{{ url_for('video_feed') }}" width="100%"> <!-- 이미지를 보여줌 -->

</div>

</div>

</div>

</body>

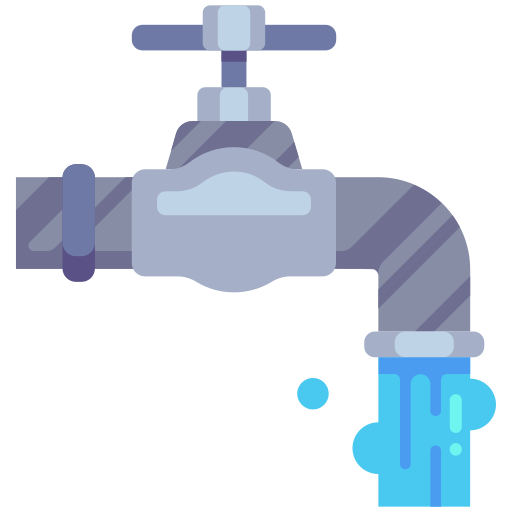
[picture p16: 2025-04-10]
앱제작파일/아이콘/faucet.png

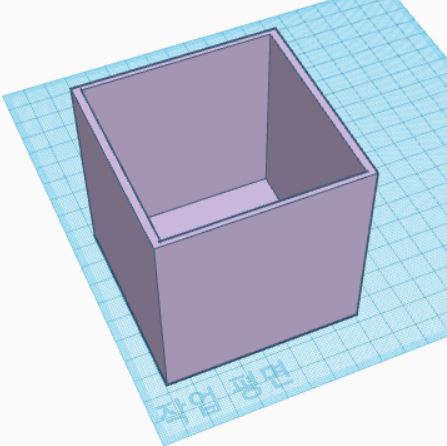
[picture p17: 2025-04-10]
3D프린터관련/물통.JPG

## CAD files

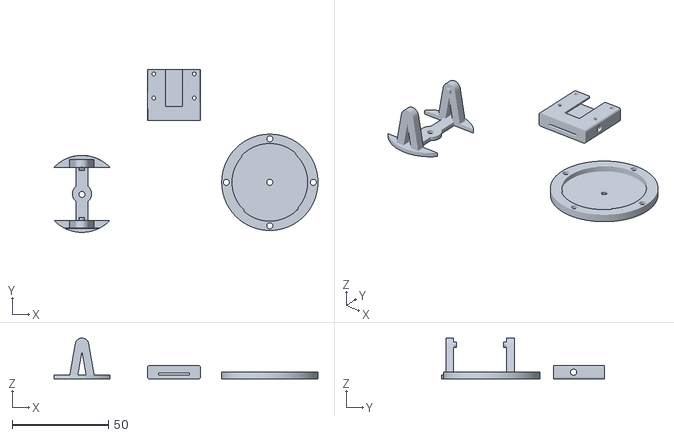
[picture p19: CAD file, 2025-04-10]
3D프린터관련/picamera.stl
137.0 x 84.5 x 21.3

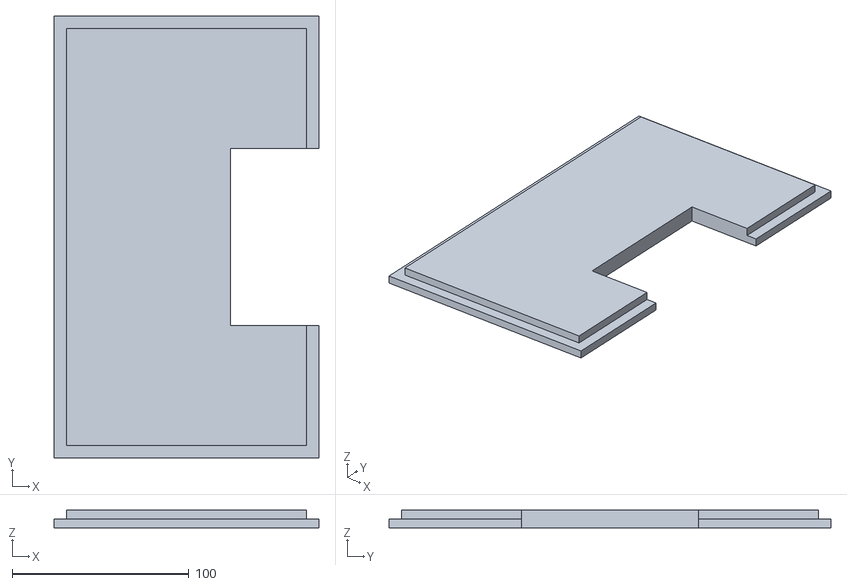
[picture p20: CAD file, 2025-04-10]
3D프린터관련/뚜껑수정.stl
150.0 x 250.0 x 10.0

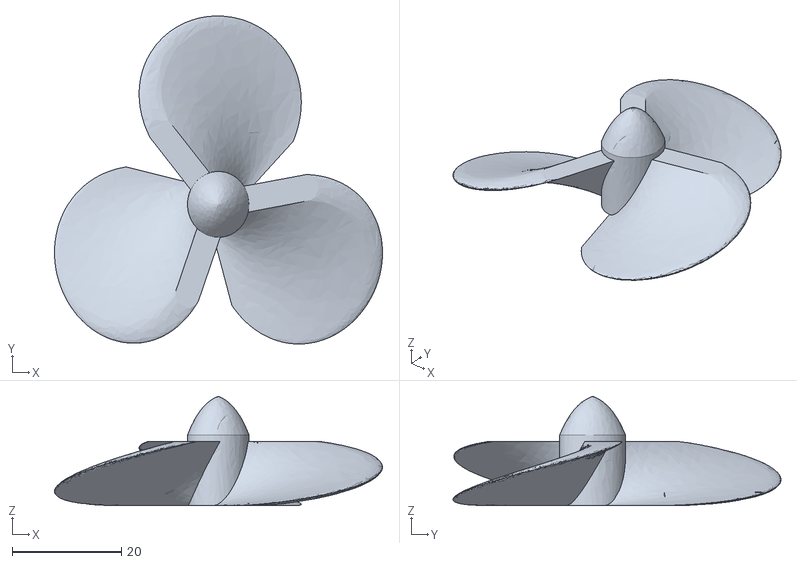
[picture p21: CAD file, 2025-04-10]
3D프린터관련/두꺼운 프로펠러.stl
60.0 x 60.0 x 20.0

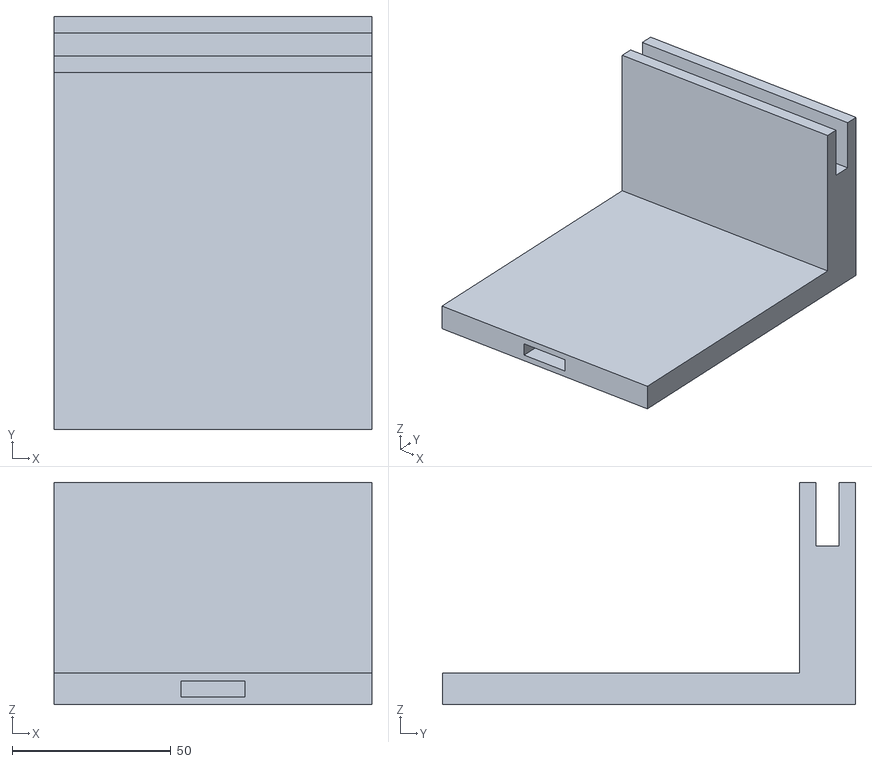
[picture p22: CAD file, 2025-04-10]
3D프린터관련/LED다리 암.stl
100.0 x 130.0 x 70.0

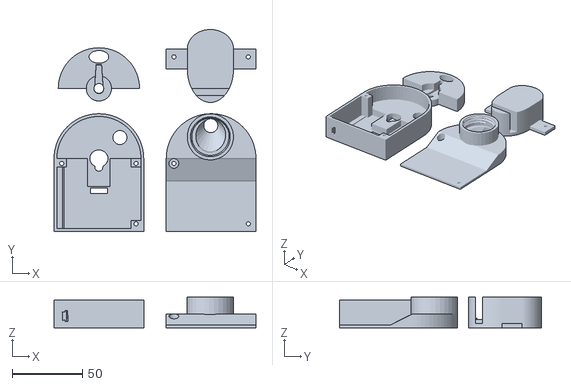
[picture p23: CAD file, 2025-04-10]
3D프린터관련/먹이공급기.stl
144.0 x 144.0 x 22.0

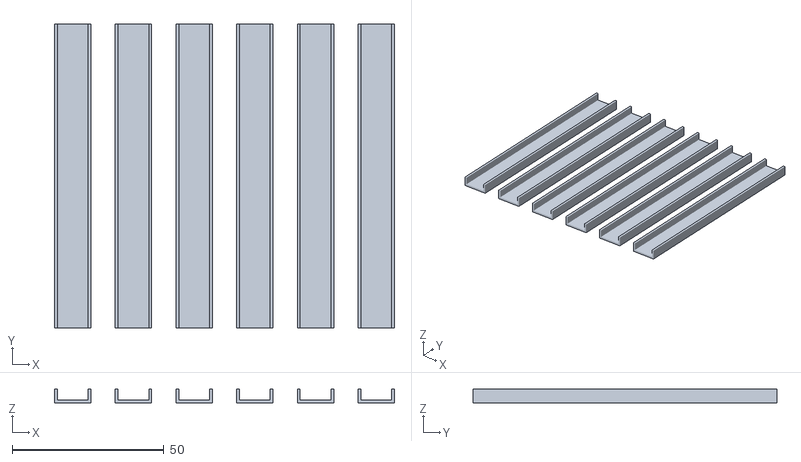
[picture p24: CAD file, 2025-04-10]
3D프린터관련/LED바6개.stl
112.0 x 100.0 x 4.50

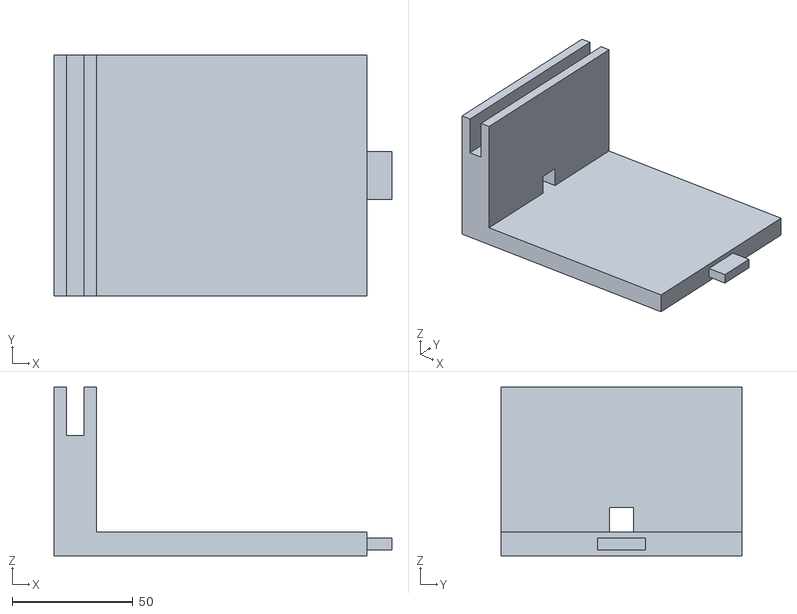
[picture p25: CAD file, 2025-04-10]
3D프린터관련/LED다리 수_수정본.stl
140.0 x 100.0 x 70.0

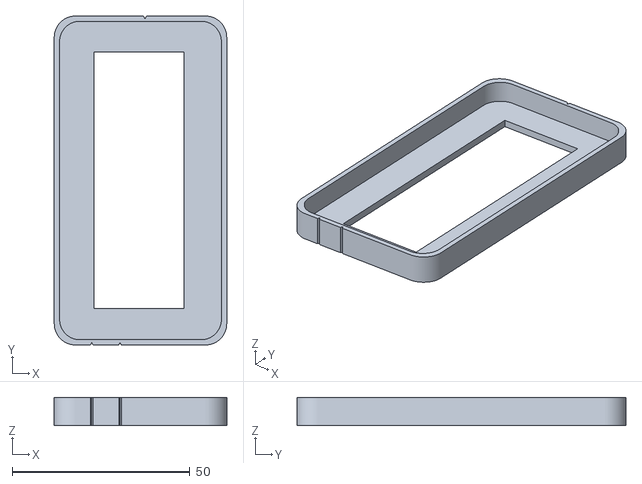
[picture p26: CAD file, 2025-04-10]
3D프린터관련/LCD케이스뚜껑.stl
48.5 x 92.5 x 8.00

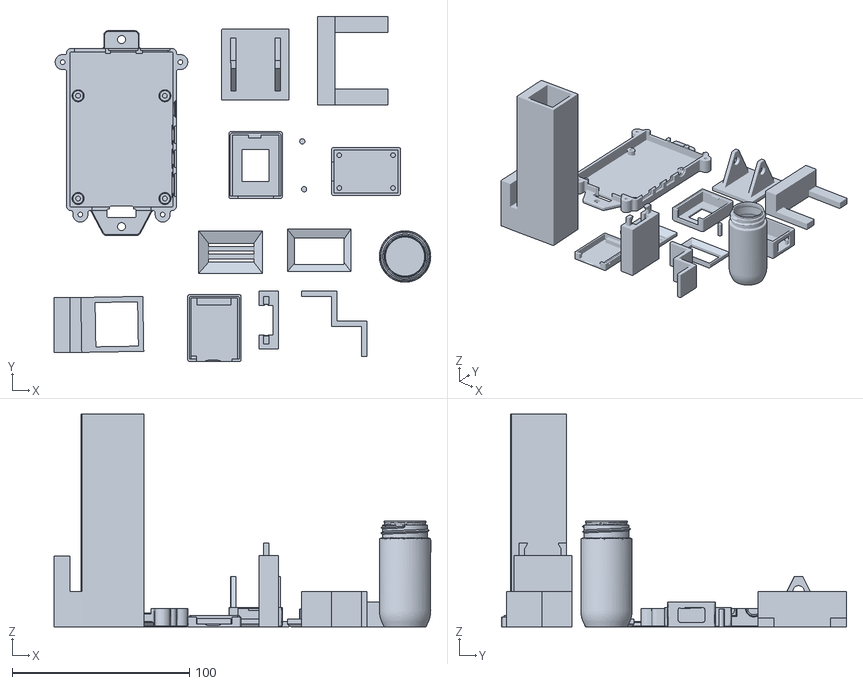
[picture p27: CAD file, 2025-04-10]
3D프린터관련/기타출력물.stl
212.5 x 194.8 x 120.0

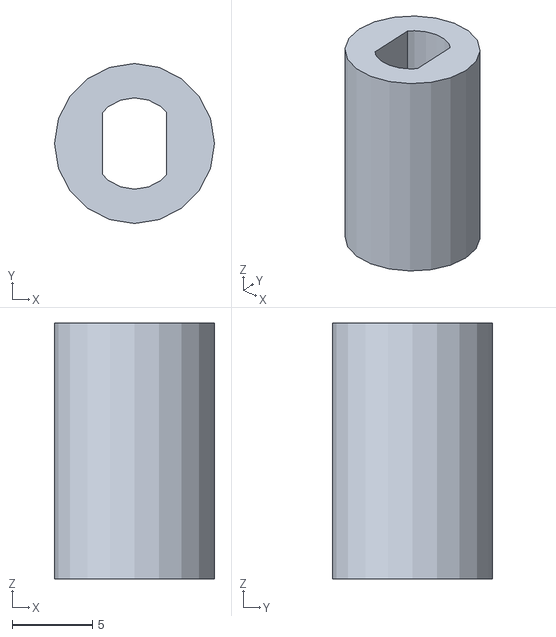
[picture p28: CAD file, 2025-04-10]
3D프린터관련/접합부.stl
10.0 x 10.0 x 16.0

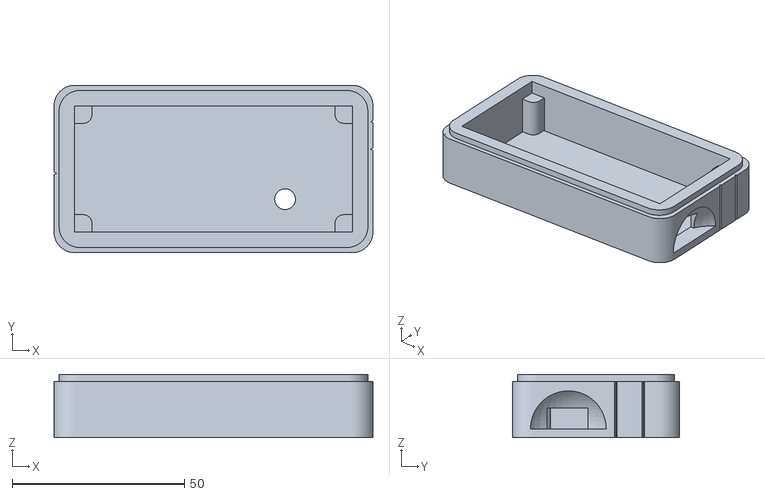
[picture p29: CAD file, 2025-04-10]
3D프린터관련/LCD케이스.stl
92.5 x 48.5 x 18.3

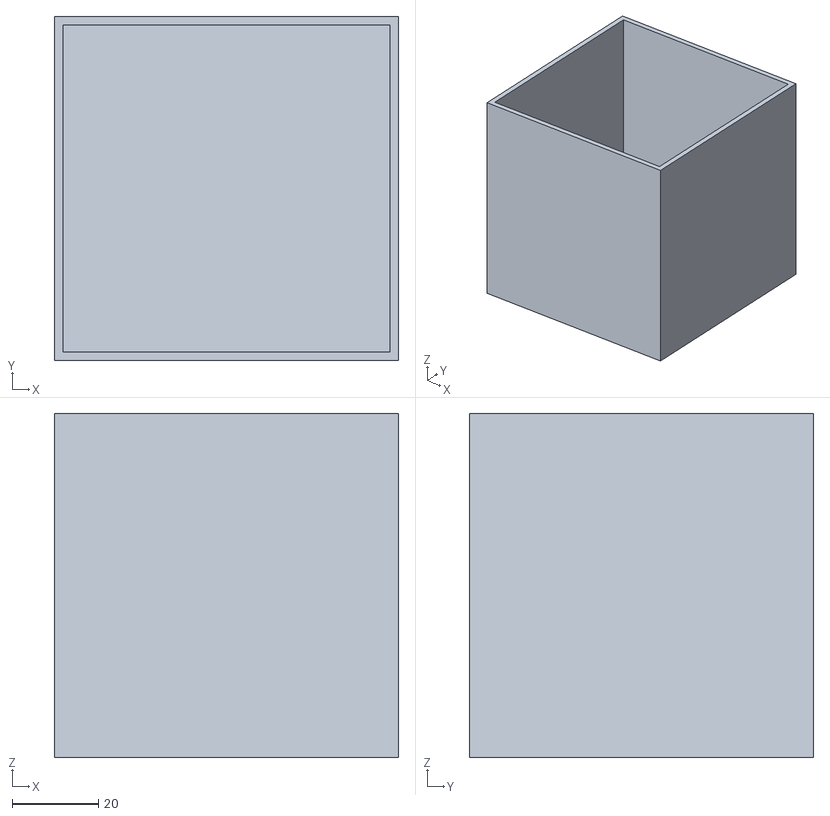
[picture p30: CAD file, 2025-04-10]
3D프린터관련/물통.stl
80.0 x 80.0 x 80.0

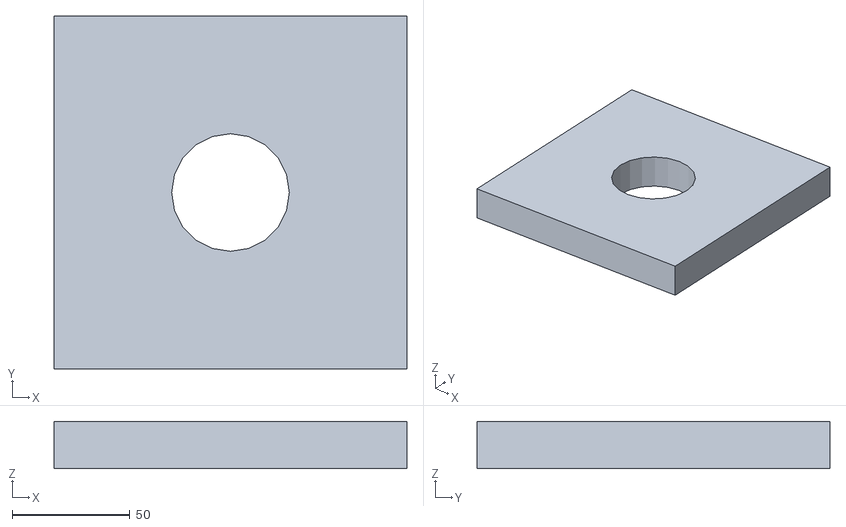
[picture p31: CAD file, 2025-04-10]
3D프린터관련/컨트롤박스 뚜껑.stl
150.0 x 150.0 x 20.0

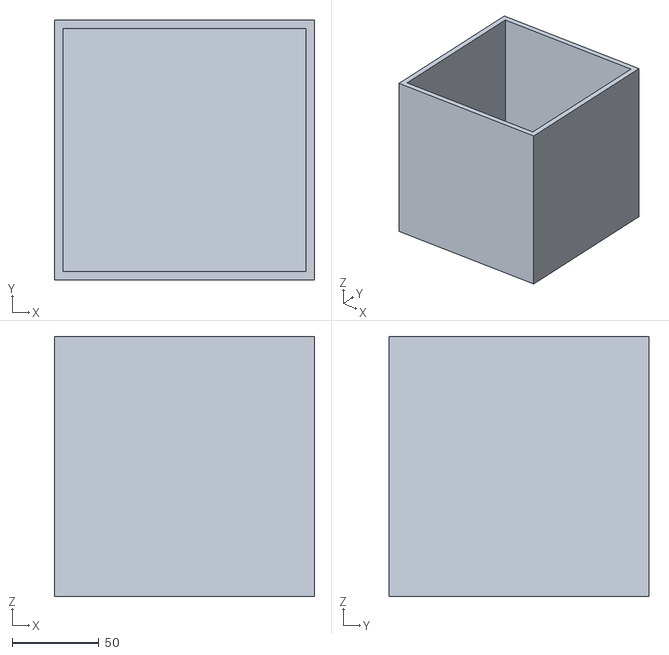
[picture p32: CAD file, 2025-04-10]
3D프린터관련/컨트롤박스 아래거.stl
150.0 x 150.0 x 150.0

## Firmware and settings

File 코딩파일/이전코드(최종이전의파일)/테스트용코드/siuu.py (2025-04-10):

import time

sensor_id = "28-fdd4451f64ff/w1_slave"

def read_temperature():
    try:
        sensor_path = f"/sys/bus/w1/devices/{sensor_id}/w1_slave"
        
        with open(sensor_path, "r") as sensor_file:
            lines = sensor_file.readlines()
            
        temperature_line = lines[1].strip()
        temperature_date = temperature_line.split(" ")[9]
        temperature = float(temperature_date[2:]) / 1000.0
        
        return temperature
    
    except Exception as e:
        print("Error reading temperature:", e)
        return None
        
while True:
    temperature = read_temperature()
    if temperature is not None:
        print("Temperature : {: .2f} C".format(temperature))
    time.sleep(1)

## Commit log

2025-04-10 라즈베리파이를 활용한 캡스톤 경진대회 우수상
    [LCD케이스.stl, LCD케이스뚜껑.stl, LED다리 수_수정본.stl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]
2025-04-10 스마트어항
